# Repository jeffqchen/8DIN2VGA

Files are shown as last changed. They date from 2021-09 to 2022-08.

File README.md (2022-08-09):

# 8DIN2VGA

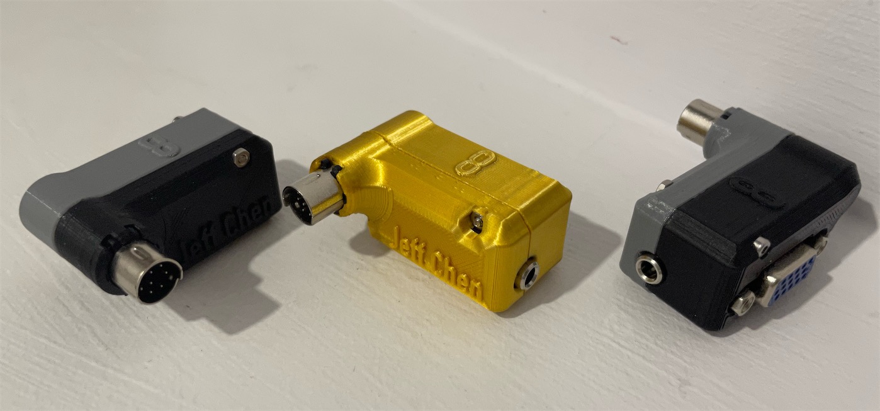
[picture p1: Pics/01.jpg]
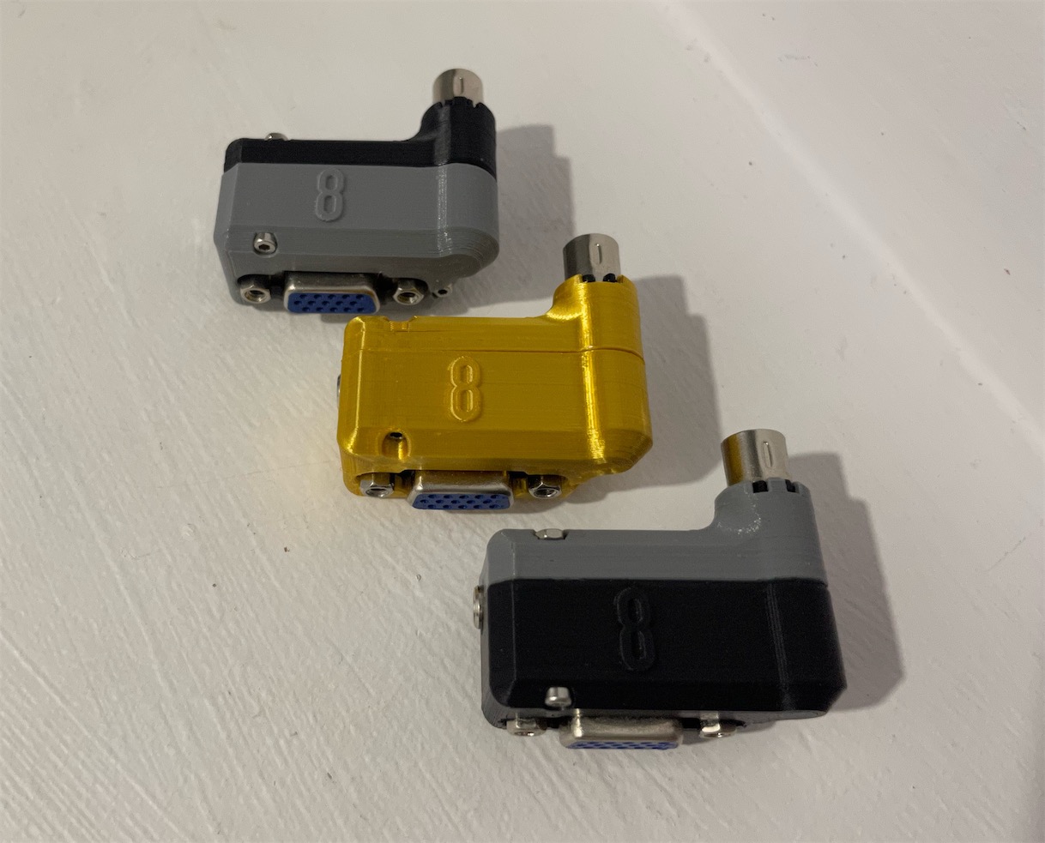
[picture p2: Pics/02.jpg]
 

A dongle for console with 8 pin Mini DIN RGBs video output.

------

This adapter allows you to plug into consoles that outputs RGBs and audio via a 8 pin Mini DIN jack and transmit the signals through a VGA cable. This includes but not limited to:
- NESRGB modded NES/Famicom
- 3DORGB modded with 3DORGB and 8 pin Mini DIN option
- Certain supergun boards

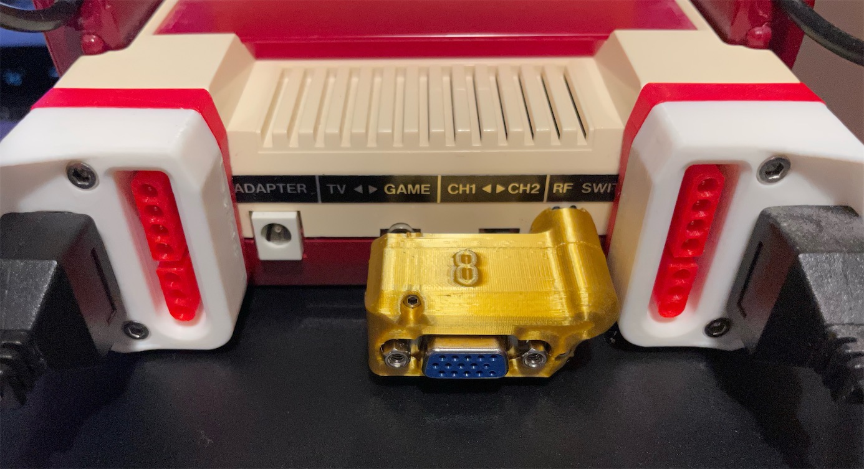
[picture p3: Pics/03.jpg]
 

 Audio can be sent within the VGA cable, or extracted from the 3.5mm jack on the dongle. Buzzing may be noticeable when audio is transmited through the VGA cable in certain scenes in certain games. This is due to insufficient shielding in most VGA cables. If you find the buzzing to be annoying, please use the 3.5mm jack on the dongle for audio output. This will ensure the cleanest possible audio.

-----------

## Different Designs

There are two types of 8 pin Mini DIN connectors you can purchase. One typically used for building cables, the other that's directly soldered to the PCB. Hence I've made two distinct designs for each of them. Comparatively speaking, the PCB-type design is easier to assemble. Otherwise, they function perfectly the same.

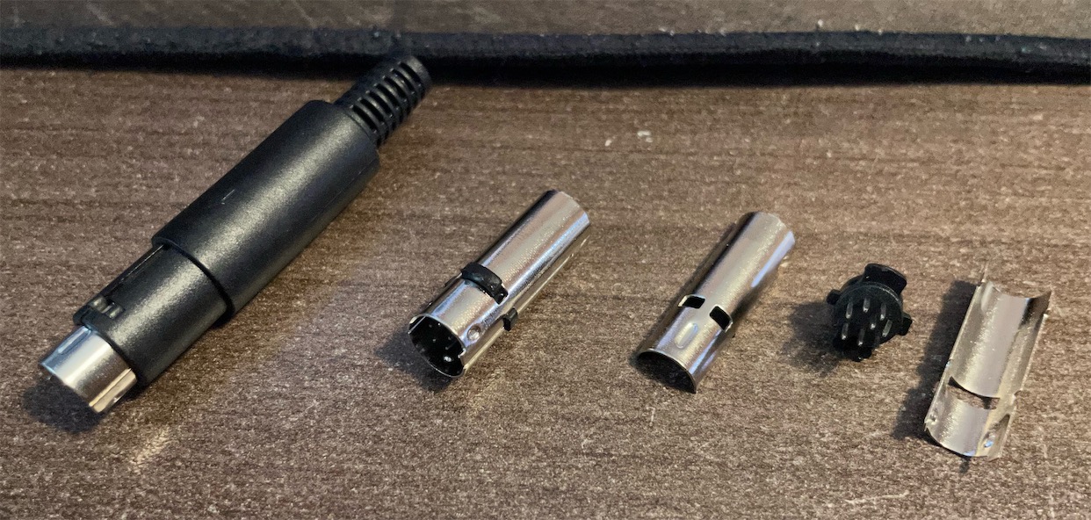
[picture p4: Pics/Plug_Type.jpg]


[Building Guide for Plug-Type 8DIN2VGA](./8DIN2VGA_Plug/README.md)

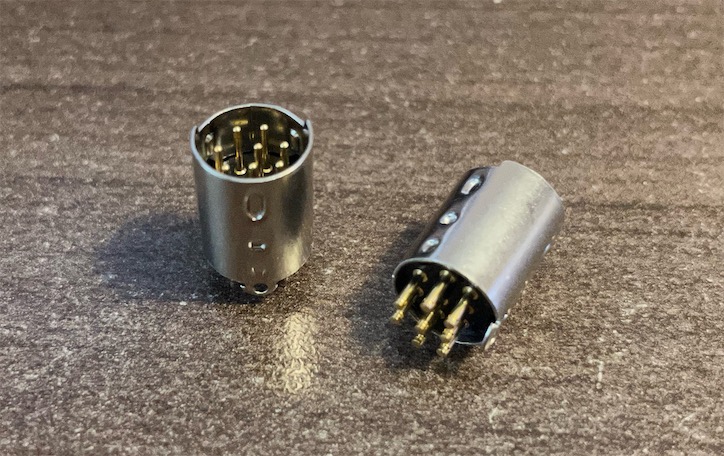
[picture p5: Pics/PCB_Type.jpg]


[Building Guide for PCB-Type 8DIN2VGA](./8DIN2VGA_PCB/README.md)

-----------

Shield: [][cc-by-sa]

This work is licensed under a
[Creative Commons Attribution-ShareAlike 4.0 International License][cc-by-sa].

[][cc-by-sa]

[cc-by-sa]: http://creativecommons.org/licenses/by-sa/4.0/
[cc-by-sa-image]: https://licensebuttons.net/l/by-sa/4.0/88x31.png
[cc-by-sa-shield]: https://img.shields.io/badge/License-CC%20BY--SA%204.0-lightgrey.svg

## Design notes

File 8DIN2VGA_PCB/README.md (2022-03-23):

# 8DIN2VGA PCB-Type
-----------
## Parts

- PCB
  - [Main](https://oshpark.com/shared_projects/Ayo7RfDd)
  - [Plug Sub PCB](https://oshpark.com/shared_projects/sRWPes9V)

- 8 pin Mini DIN Male (PCB Type) - Choose the "8 Pin" option - [Link](https://github.com/jeffqchen/JeffParts/blob/main/Connectors/Mini%20DIN/8Pin/Through%20Hole/info.md)

*Note: the "9 Pin" option is incompatible with the Genesis, if you are wondering. Don't buy it.*

- VGA Port Slim Female - [Link](https://github.com/jeffqchen/JeffParts/blob/main/Connectors/HD15/Slim/Female%20PCB/info.md)

- 3.5mm Headphone Jack - [Link](https://github.com/jeffqchen/JeffParts/blob/main/Connectors/3.5mm%20Audio%20Jack/Vertical%205-Pin%20PCB/info.md)

- [1x] ]M2x20mm and [1x] M2x16mm screw and hex nut - [Link](https://github.com/jeffqchen/JeffParts/blob/main/Parts/M2%20M3%20Hex%20Screw%20%26%20Nut/info.md)

- 2x SMD Capacitor 10uF 6.3V 0603 size

- 3D Printed Case and Insert

-----------
## Print

Print the parts in their original orientations, with the mating surface downwards. Print with support.

-----------
## Assembly

Trim all the extra tabs on the PCB and file them flush to ensure an easy assembly.

First, insert the main PCB golden fingers into the plug PCB as indicated in the photos.

Adjust the position to ensure the mating is flush. If not, try filing off some more of the PCB.

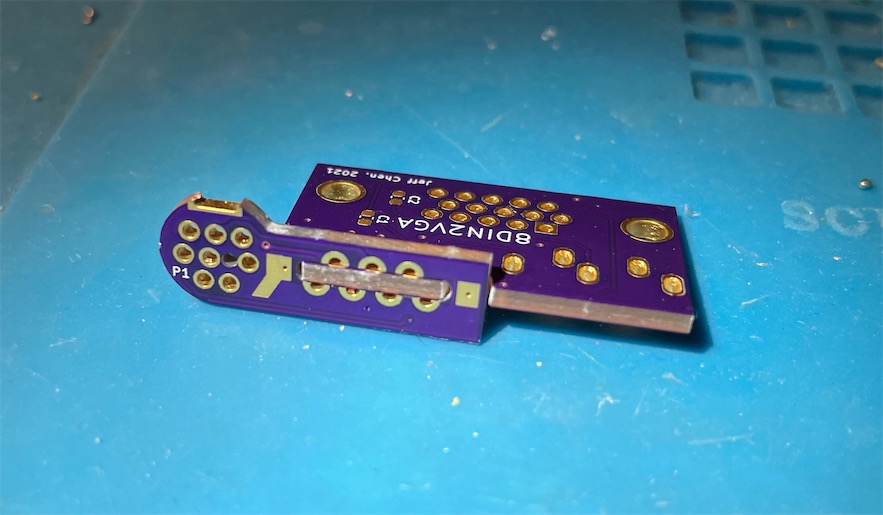
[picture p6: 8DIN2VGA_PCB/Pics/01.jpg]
 

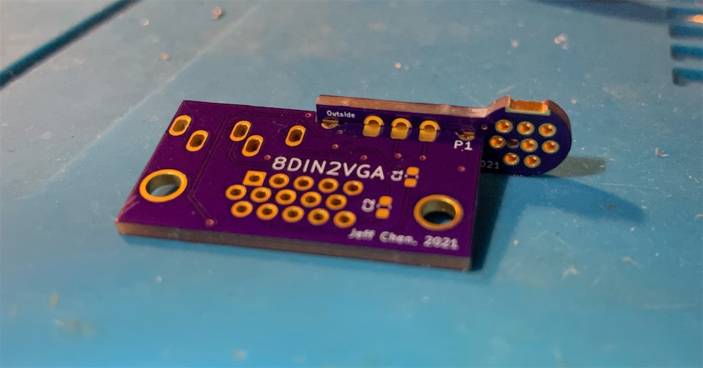
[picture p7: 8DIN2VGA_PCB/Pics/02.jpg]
 

Make sure the main and the plug PCBs are perpendicular. Then tac it down by soldering only one contact. Then inspect again. If something is not right, adjust while keeping your iron on the soldered joint to keep it molten.

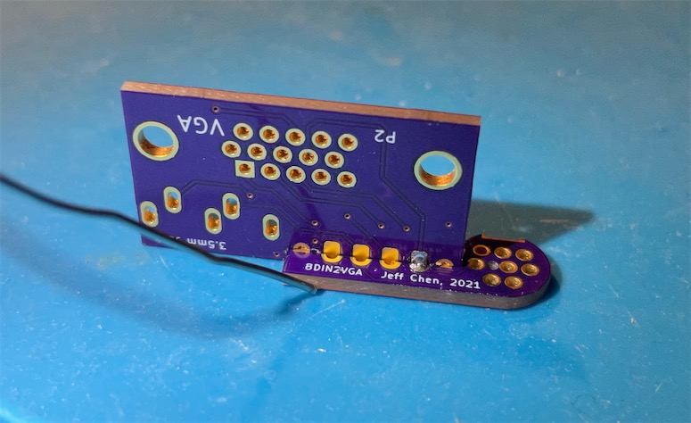
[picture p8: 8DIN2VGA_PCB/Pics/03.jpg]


Once satisfied, solder down all the contacts between the main and the plug PCB. Then solder on the 0603 10uF capacitors onto the main PCB .

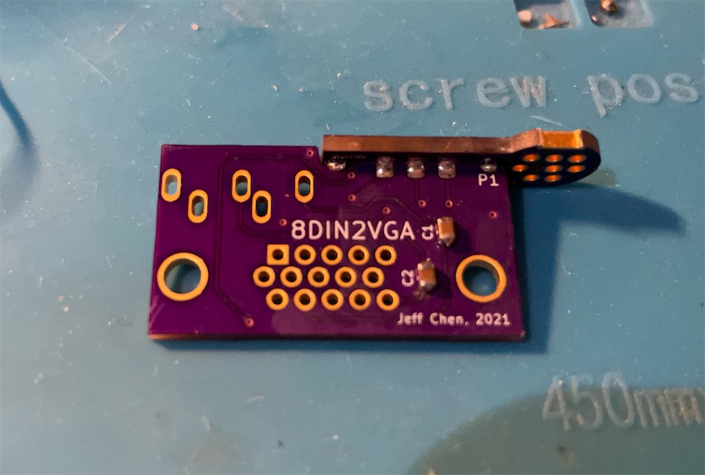
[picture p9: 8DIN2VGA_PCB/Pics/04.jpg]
 

Insert the 8 pin DIN plug into the plug PCB. Tac one joint down with solder.

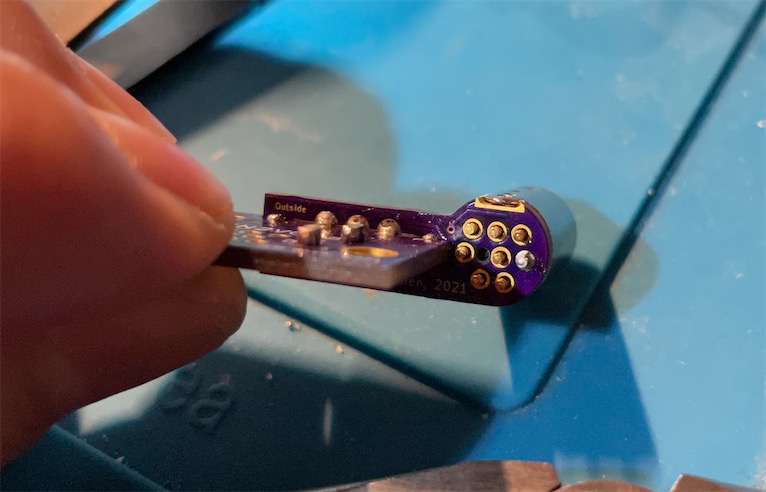
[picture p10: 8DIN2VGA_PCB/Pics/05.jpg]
 

 Check if the plug is soldered on straight, adjust if necessary.

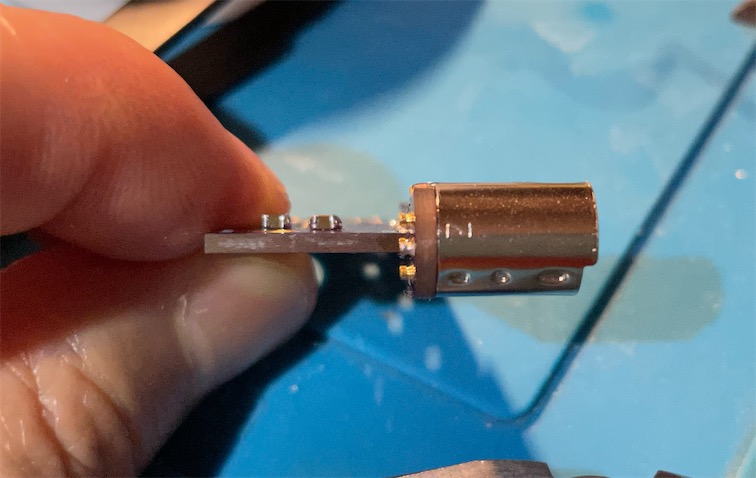
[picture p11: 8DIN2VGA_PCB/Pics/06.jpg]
 

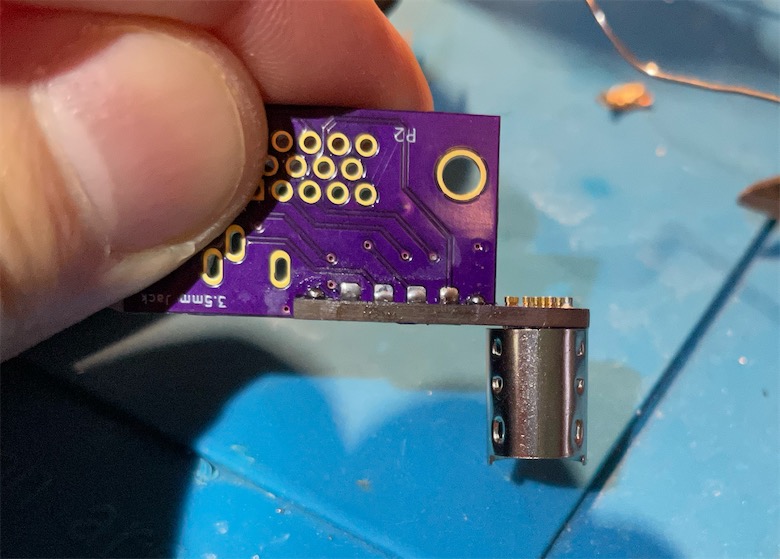
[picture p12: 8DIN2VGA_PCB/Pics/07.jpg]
 

Then solder all the contacts of the plug to the PCB.

Right next to the plug, on the PCB, there is an exposed area of copper. Drown it with copper and solder it to the metal shielding to add more mechanical strength to the assembly.

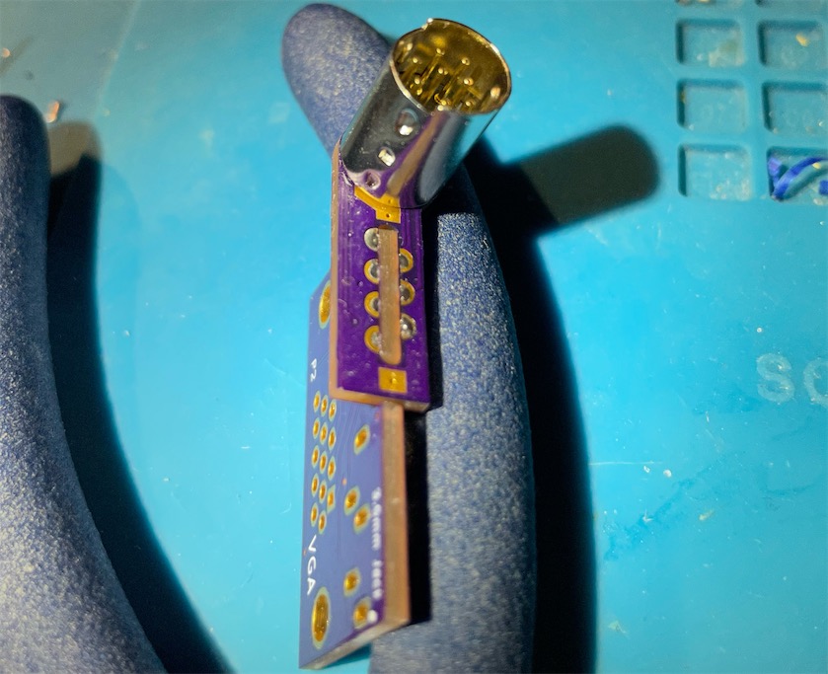
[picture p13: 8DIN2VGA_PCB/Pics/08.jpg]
 

 Don't forget to solder the metal tab on top of the shielding to the PCB for even more strength.

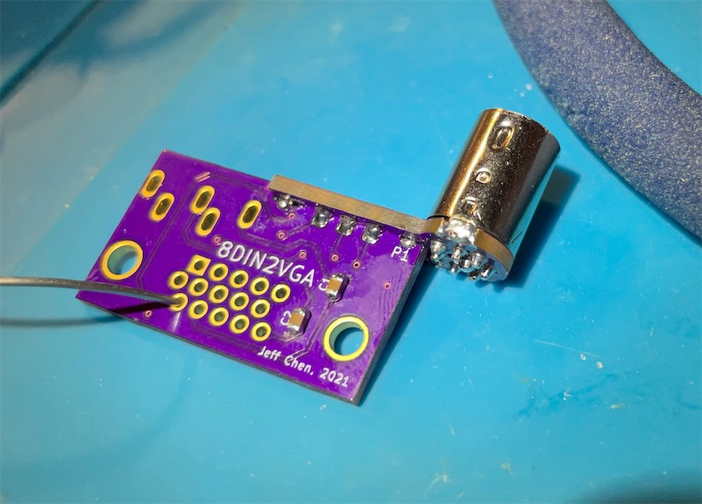
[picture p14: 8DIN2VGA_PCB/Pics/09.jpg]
 

 Insert the 3.5mm jack into the PCB. Solder it down by only one lead and adjust it to make sure it's flush to the PCB. Then solder all the contacts.

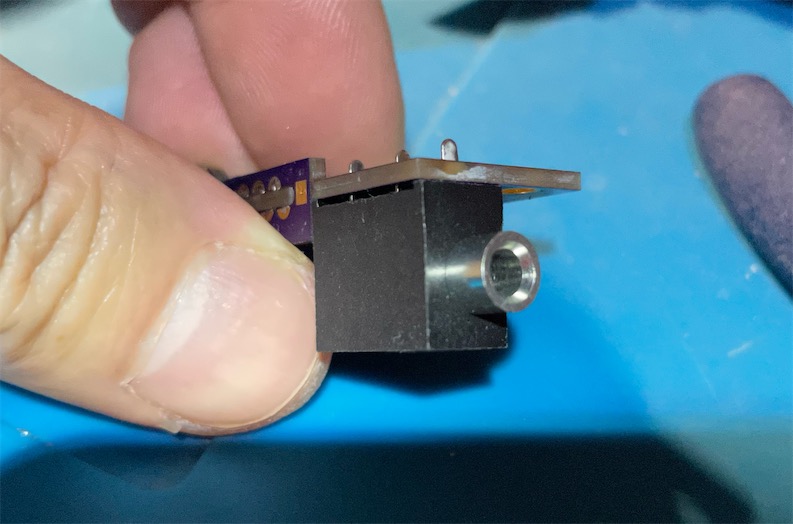
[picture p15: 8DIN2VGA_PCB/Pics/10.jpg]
 

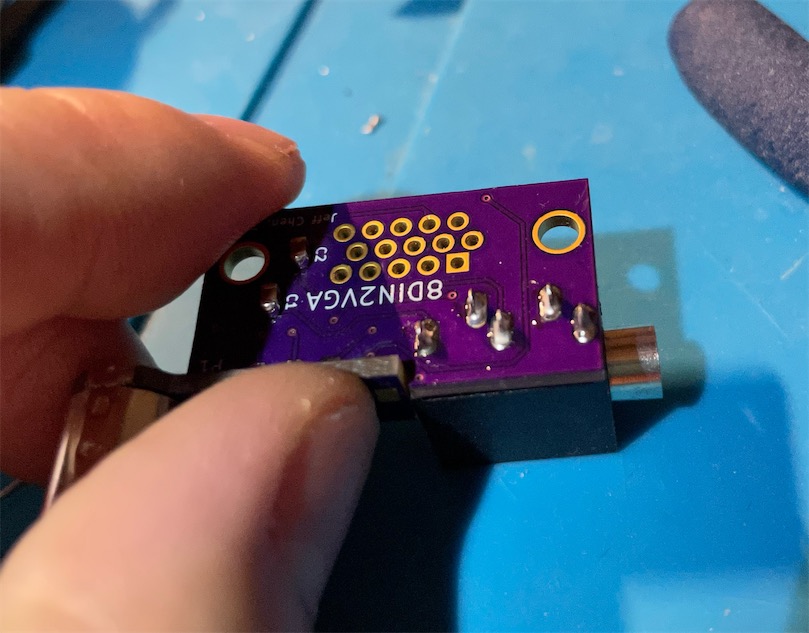
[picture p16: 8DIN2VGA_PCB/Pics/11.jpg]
 

Insert the assembly into the inside shell. You might have to push a bit hard if the printing tolerance is tight. Then, fit in the 3D printed insert piece. It should be flush with the outside of the 3.5mm jack.

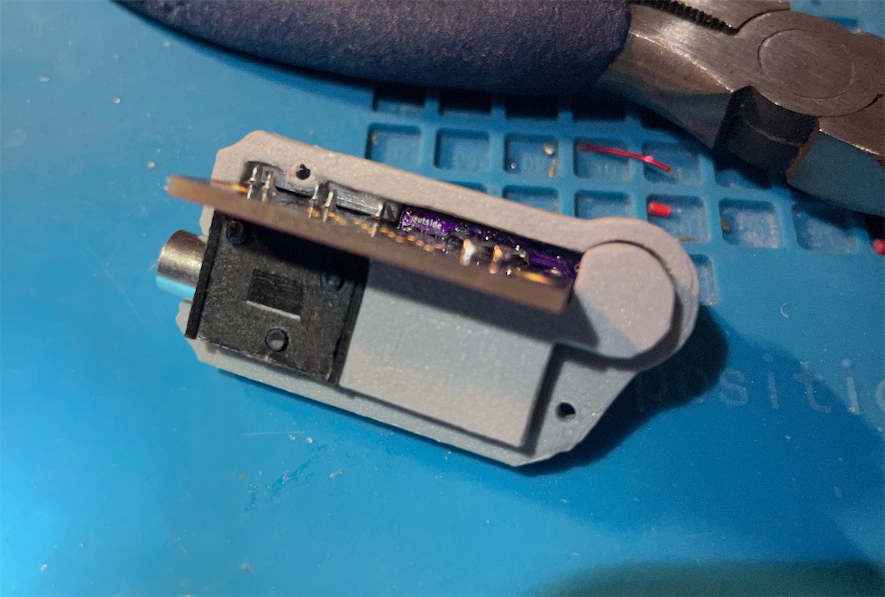
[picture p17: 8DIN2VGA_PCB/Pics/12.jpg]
 
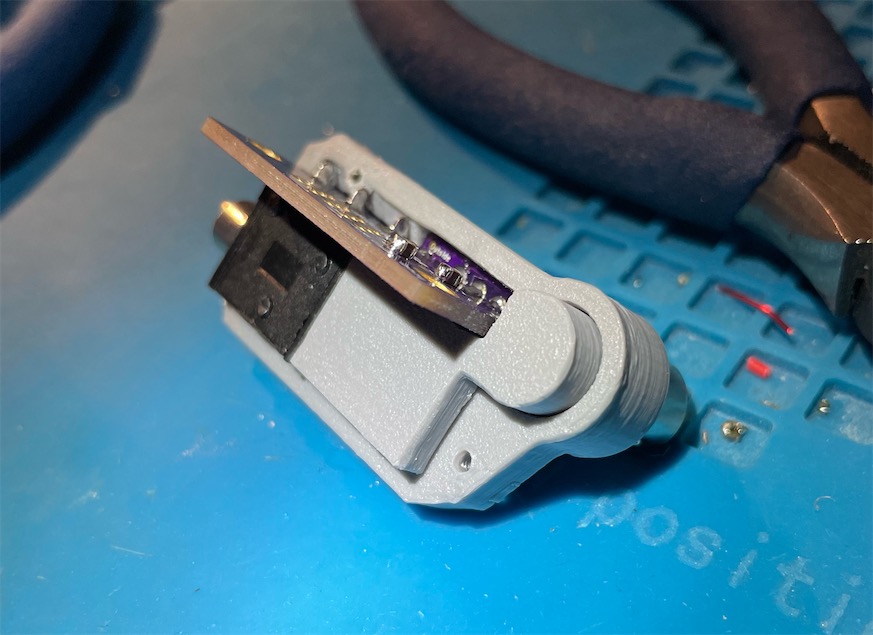
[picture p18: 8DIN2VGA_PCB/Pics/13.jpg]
 

Test fit the outside shell and see if the shells close nicely together. If not, check the fitment.

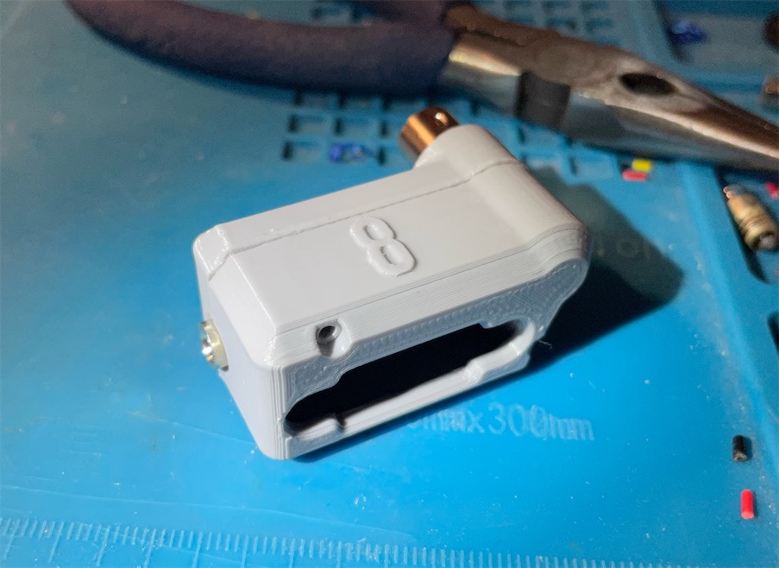
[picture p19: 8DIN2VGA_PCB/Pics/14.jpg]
 

Open the shell back up and finally, solder in the VGA port.

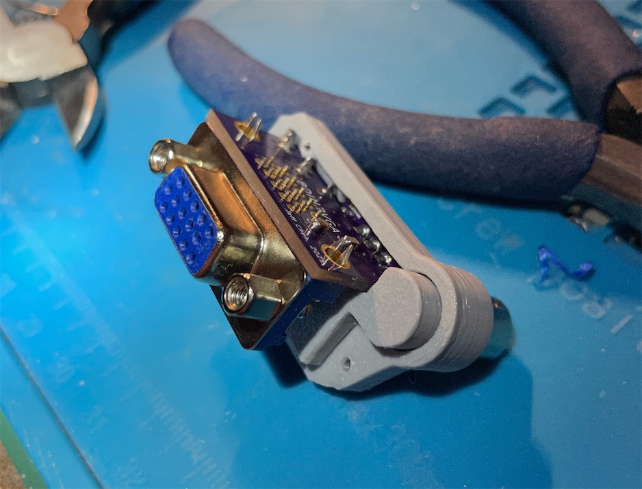
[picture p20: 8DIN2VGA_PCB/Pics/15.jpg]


Alternatively, you can slide out the entire assembly and solder the VGA port. It's also easier to test in this state.

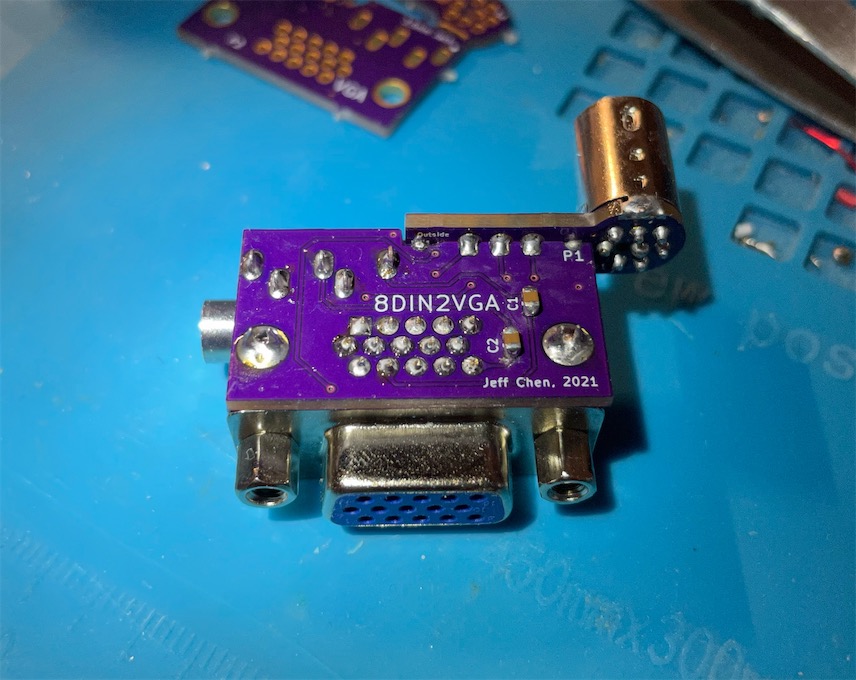
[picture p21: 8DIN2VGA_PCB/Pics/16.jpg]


Remember to put in the insert piece inside when you close up the shell.

If nuts don't want to fit nicely into the shell, twist a screw onto it and use it as a handle and try to press the nut in place from the outside.

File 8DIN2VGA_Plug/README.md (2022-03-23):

# 8DIN2VGA Plug-Type
-----------

## Parts

- PCB
  - [Main](https://oshpark.com/shared_projects/XZ4A1SB4)
  - [Top Sub **0.8mm thickness**](https://oshpark.com/shared_projects/FF7H08du)
  - [Bottom Sub **0.8mm thickness**](https://oshpark.com/shared_projects/HFqqnMif)

*Note the Top & Bottom sub boards MUST be ordered with the 0.8mm thickness option, otherwise they won't fit!*

- 8 pin Mini DIN Male (Plug Type) - [Link](https://github.com/jeffqchen/JeffParts/blob/main/Connectors/Mini%20DIN/8Pin/Cable/info.md)

- VGA Port Slim Female - [Link](https://github.com/jeffqchen/JeffParts/blob/main/Connectors/HD15/Slim/Female%20PCB/info.md)

- 3.5mm Headphone Jack - [Link](https://github.com/jeffqchen/JeffParts/blob/main/Connectors/3.5mm%20Audio%20Jack/Vertical%205-Pin%20PCB/info.md)

- M2x20mm screw and hex nut - [Link](https://github.com/jeffqchen/JeffParts/blob/main/Parts/M2%20M3%20Hex%20Screw%20%26%20Nut/info.md)

- 2x SMD Capacitor 10uF 6.3V 0603 size

-----------
## Print

Print the parts with the mating surface downwards, with support.

-----------
## Assembly

Soldering in this project is essential and somewhat challenging. This applies to soldering the sub boards to the pin header, as well as the landing pads on the main PCB. If you leave any gap, the assembly will not fit and the shells won't close properlly.

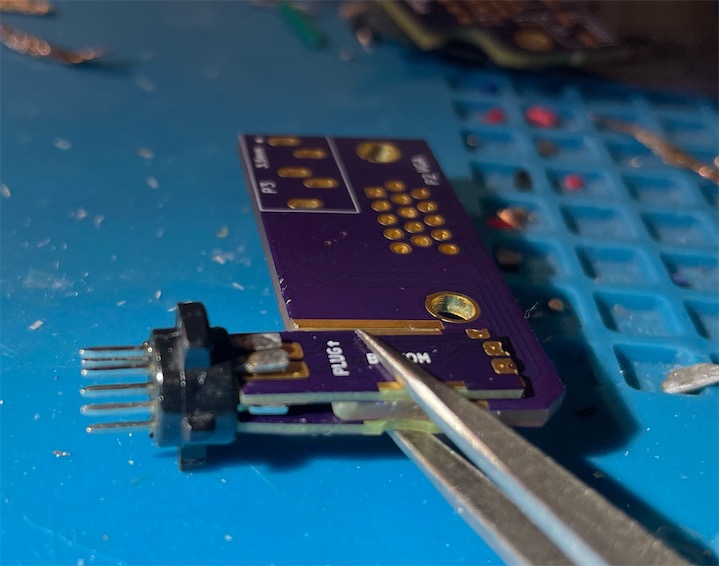
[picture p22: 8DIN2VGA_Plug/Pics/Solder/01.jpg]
 
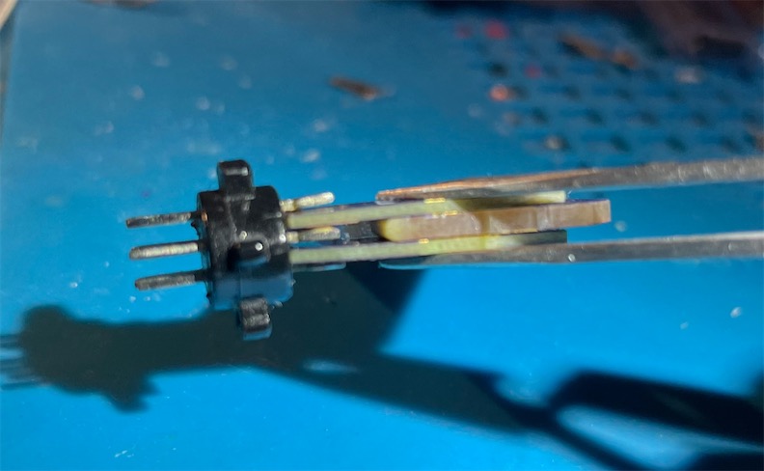
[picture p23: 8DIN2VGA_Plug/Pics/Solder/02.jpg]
 

 First, put the 3 boards together in their final position, and fix the assembly with the help from reverse tweezers or clamps. Try and fit the 0.8mm PCBs in between the gaps between the back side of the 3 rows of pins. Push the sub PCBs all the way until they touch the pin header. Make sure the pins and their pads are aligned properlly.

 ----

 ## IMPORTANT

 *The plastic of the plug pin header is weak against heat and should not be heated for more than a few seconds in one go. Try to cool it down between soldering by blowing air on it.*

 ----

 Solder the two pins on the bottom side of the bottom PCB with proper amount of solder. Then release the clamping and remove the top and main PCB. Proceed to solder the center row of the pins to the bottom PCB.

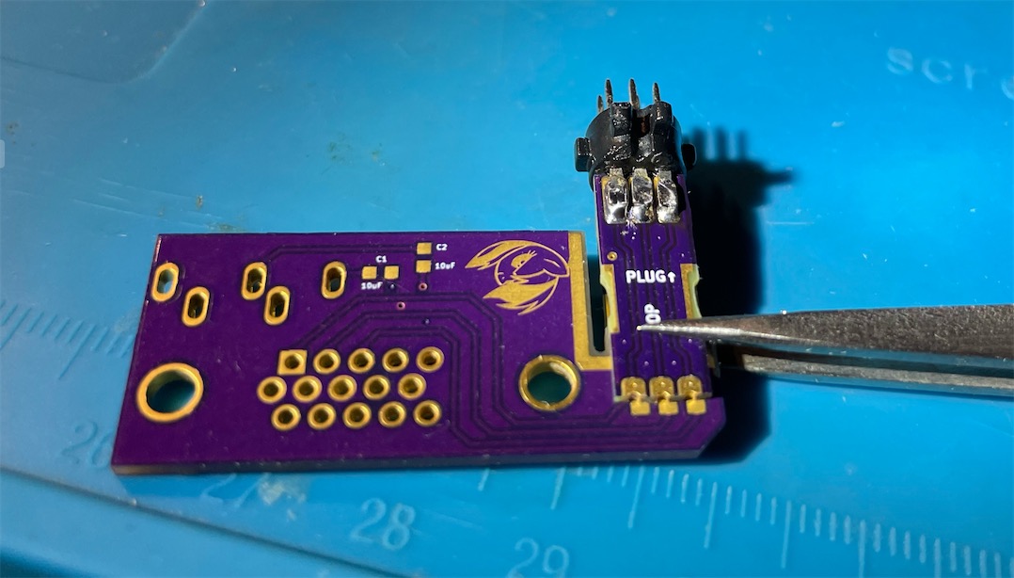
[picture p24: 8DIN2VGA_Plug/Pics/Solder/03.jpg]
  

 Again, put everything back together with clamping. Then, solder the top PCB to the top row of the pin header. Now, release the clamping and remove only the main PCB. The assembly should look as follows:

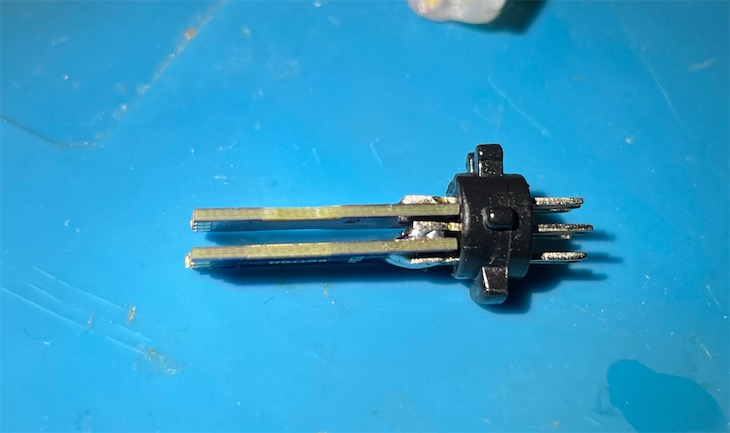
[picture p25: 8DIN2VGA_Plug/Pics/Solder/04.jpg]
 

 Now, put the 2 pieces of metal shielding over the pin header part:

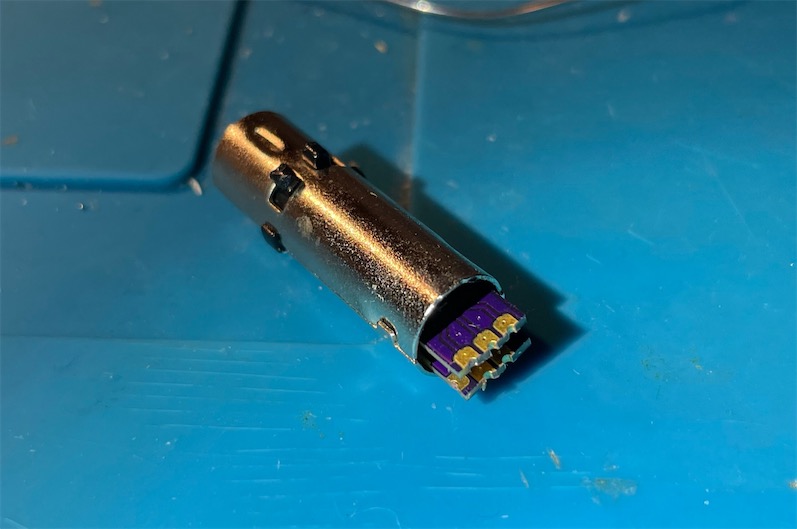
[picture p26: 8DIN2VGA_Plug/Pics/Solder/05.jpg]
 

 Shove the assembly through the round hole on the inside shell, all the way in:

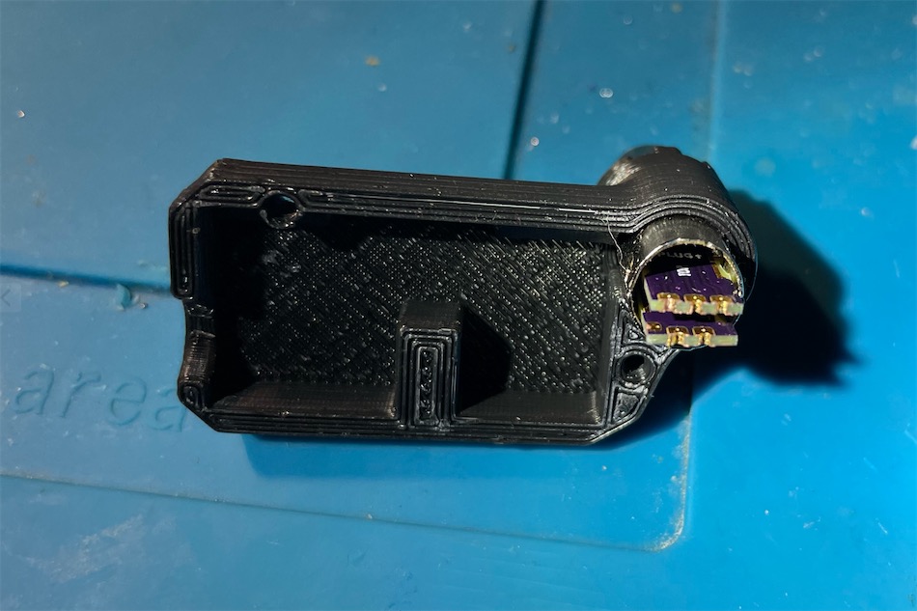
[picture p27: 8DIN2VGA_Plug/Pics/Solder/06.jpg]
 

 Test fit the main PCB firmly into the shell and the plug and see if all the landing pads line up correctly:

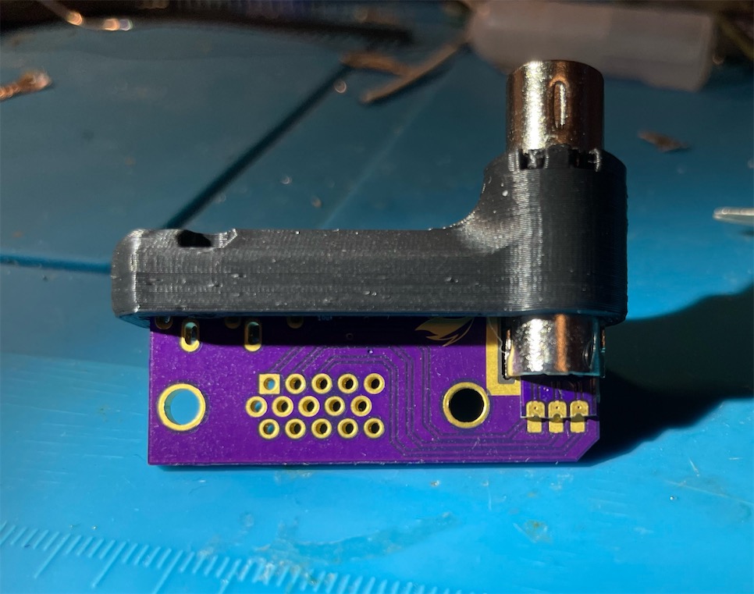
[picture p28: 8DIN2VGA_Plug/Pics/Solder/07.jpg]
 
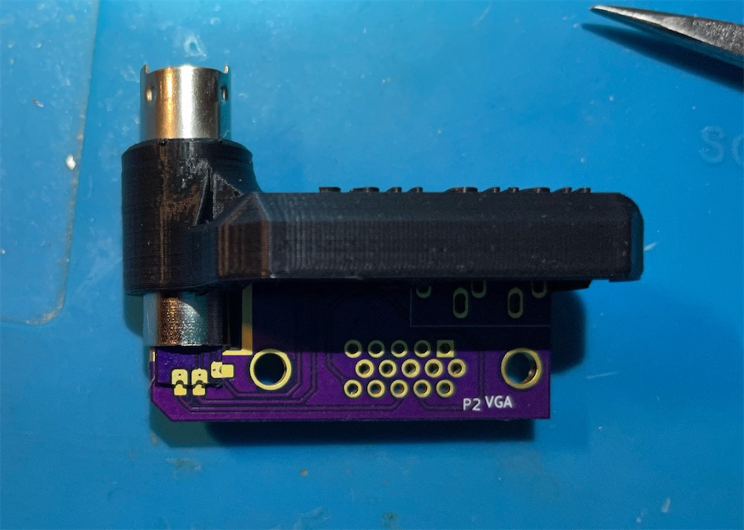
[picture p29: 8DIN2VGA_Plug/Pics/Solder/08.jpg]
 

 Now, take out the main PCB and solder on the 10uF SMD caps and the headphone jack:

 

 Again, insert the main PCB into its final position. Pinch the two sub boards into the main with a clapm or reverse tweezers. Make sure there's no gap between the sub and main PCB. Then, solder all the landing pads with proper amount of solder.

 
 

 Then, use ample amount of solder to attach the metal shield of the plug to the exposed copper area onto both sides of the main PCB。

 
 

 Last, solder in the VGA port. Soldering is done.



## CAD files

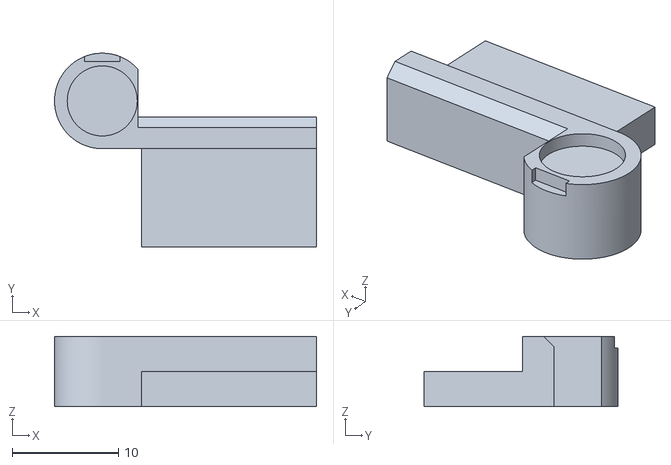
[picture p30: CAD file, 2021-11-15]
8DIN2VGA_PCB/3D Print/Insert.stl
24.7 x 18.2 x 6.60

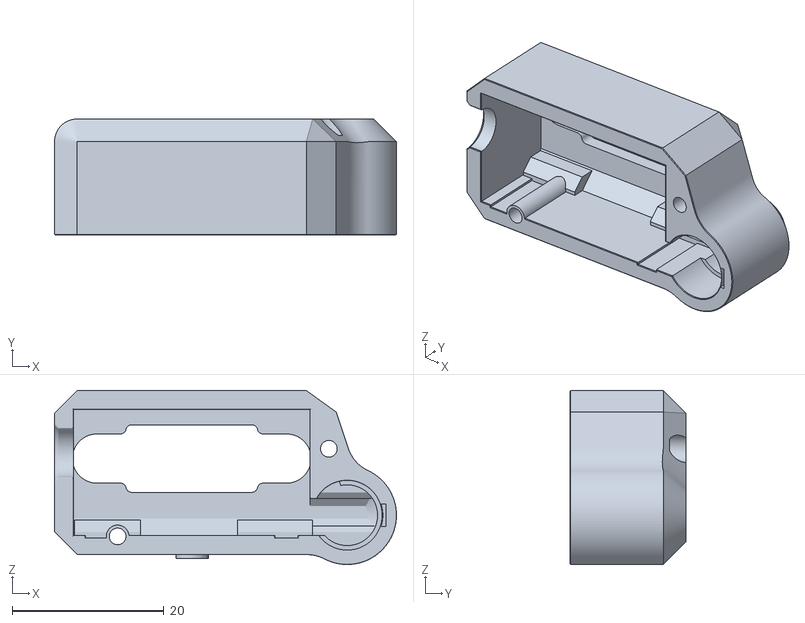
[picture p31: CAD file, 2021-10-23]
8DIN2VGA_Plug/3D Print/Outside.stl
45.1 x 15.3 x 22.9

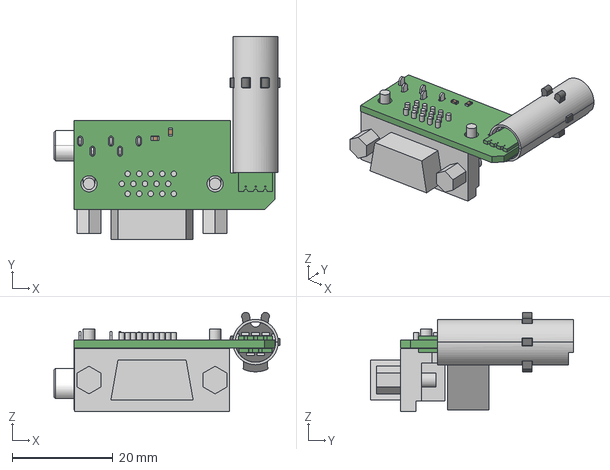
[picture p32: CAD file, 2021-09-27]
8DIN2VGA_Plug/KiCAD/8DIN2VGA.step
44.8 x 40.3 x 19.7 mm

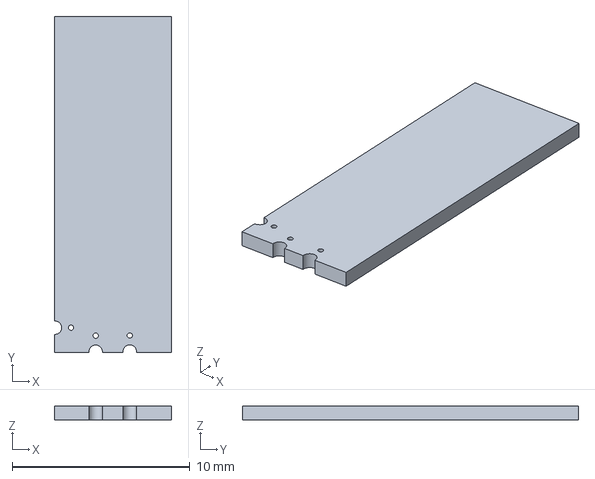
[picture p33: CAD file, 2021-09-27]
8DIN2VGA_Plug/KiCAD/8DIN2VGA_Bottom/8DIN2VGA_Bottom.step
6.61 x 18.9 x 0.8 mm

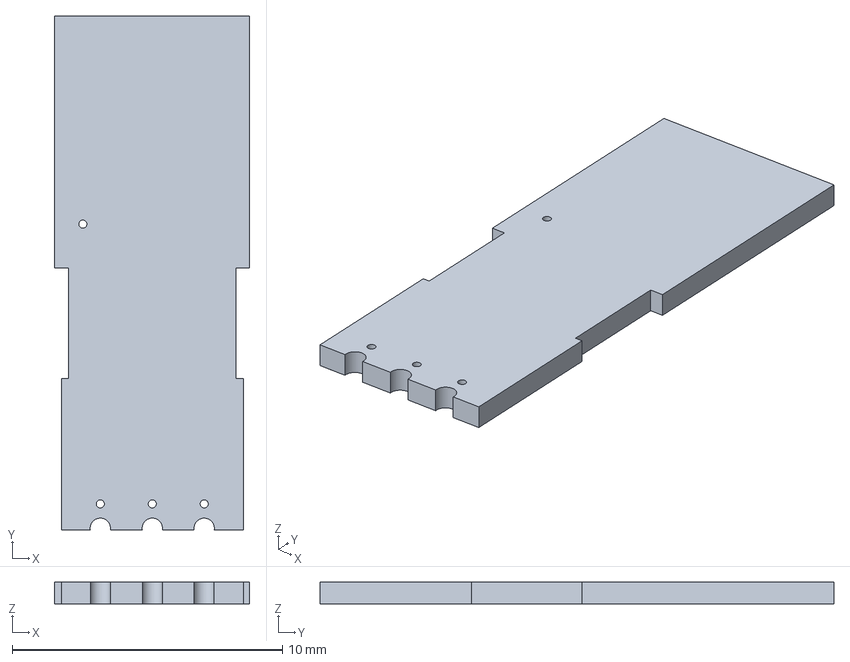
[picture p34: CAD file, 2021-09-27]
8DIN2VGA_Plug/KiCAD/8DIN2VGA_Top/8DIN2VGA_Top.step
7.22 x 19.0 x 0.8 mm

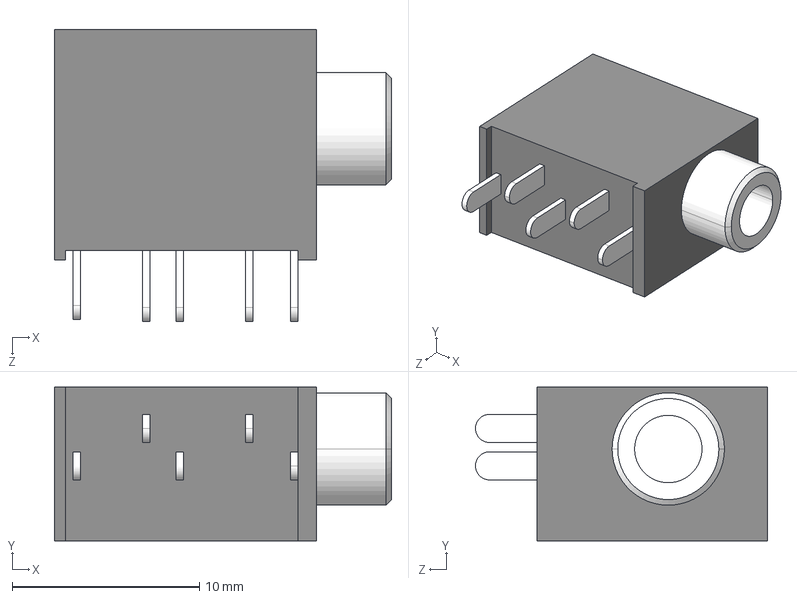
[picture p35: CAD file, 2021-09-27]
8DIN2VGA_Plug/KiCAD/Materials/3.5MM_vertical_SJ1-3535N/3.5MM_vertical_SJ1-3535N_3D/CUI_DEVICES_SJ1-3535N.step
18.0 x 8.20 x 15.6 mm

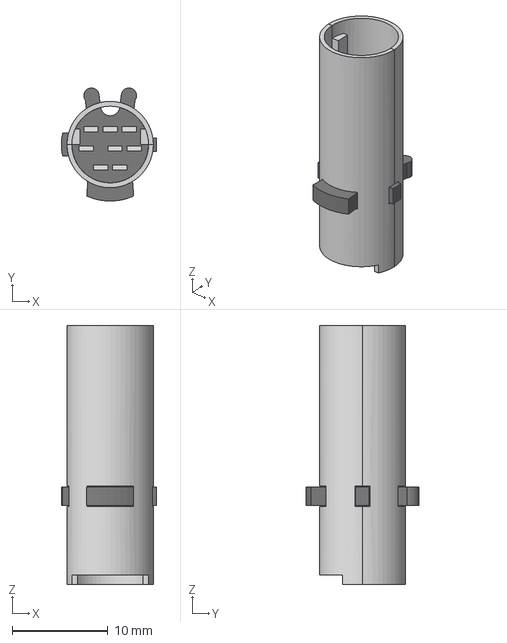
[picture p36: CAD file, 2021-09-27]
8DIN2VGA_Plug/KiCAD/Materials/Mini DIN 8 pin.step
9.95 x 11.8 x 27.0 mm
Shield Top
Shield Bottom

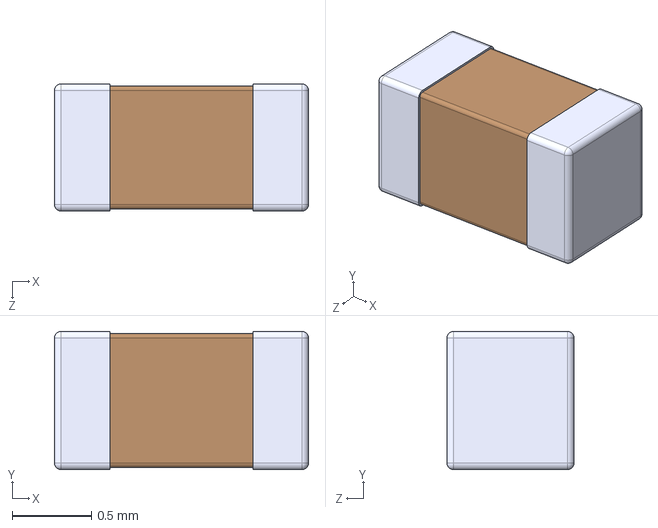
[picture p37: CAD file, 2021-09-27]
8DIN2VGA_Plug/KiCAD/Materials/SMD_Cap/C0603C180K4HAC7867.step
1.60 x 0.87 x 0.8 mm

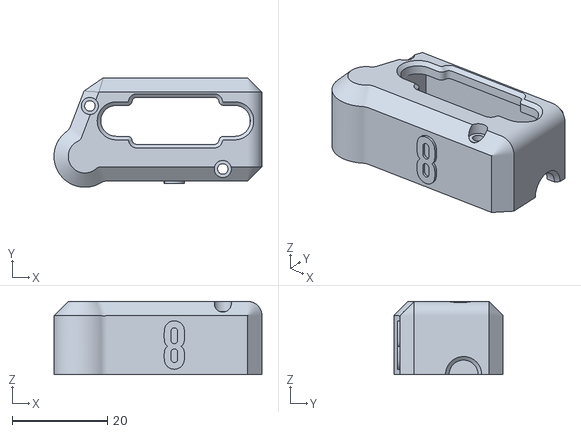
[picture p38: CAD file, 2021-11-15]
8DIN2VGA_PCB/3D Print/Shell Outside.stl
43.8 x 23.0 x 15.4

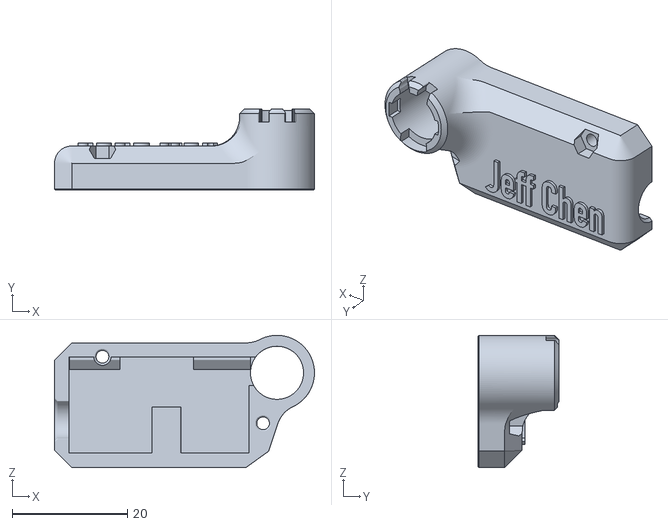
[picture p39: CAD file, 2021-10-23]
8DIN2VGA_Plug/3D Print/Inside.stl
45.1 x 14.0 x 22.9

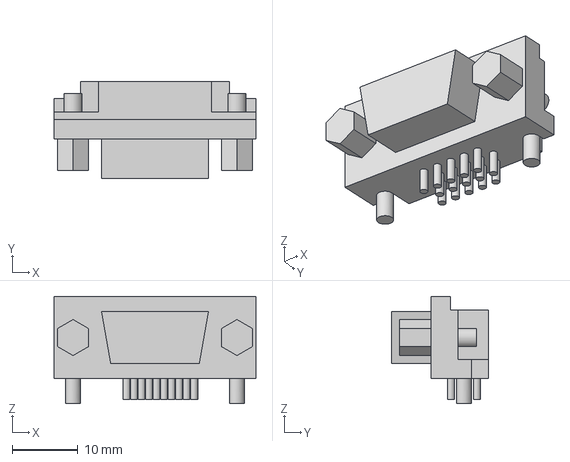
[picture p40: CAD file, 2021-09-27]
8DIN2VGA_Plug/KiCAD/Materials/VGA Female Slim.step
30.8 x 14.8 x 16.4 mm

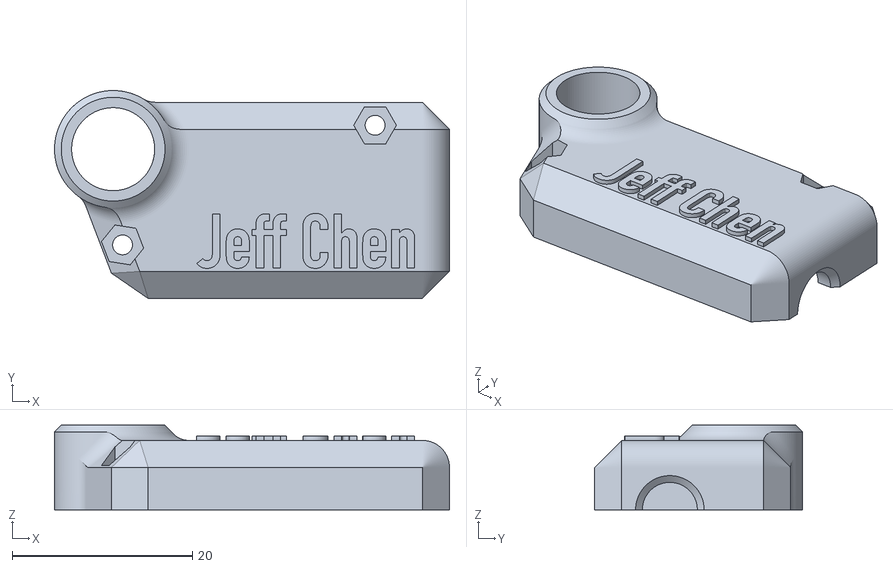
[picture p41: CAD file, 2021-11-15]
8DIN2VGA_PCB/3D Print/Shell Inside.stl
43.8 x 23.0 x 9.40

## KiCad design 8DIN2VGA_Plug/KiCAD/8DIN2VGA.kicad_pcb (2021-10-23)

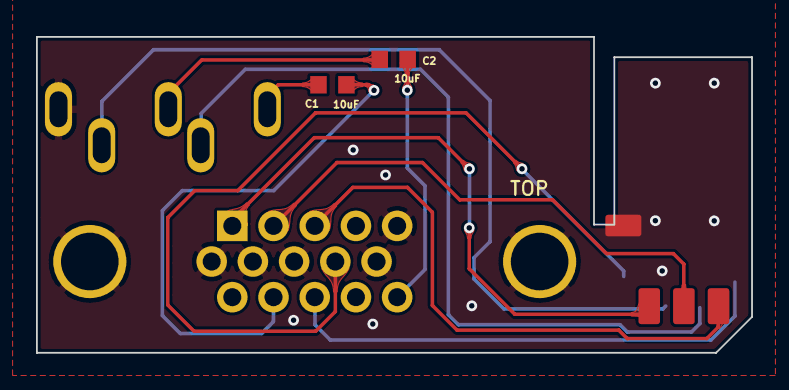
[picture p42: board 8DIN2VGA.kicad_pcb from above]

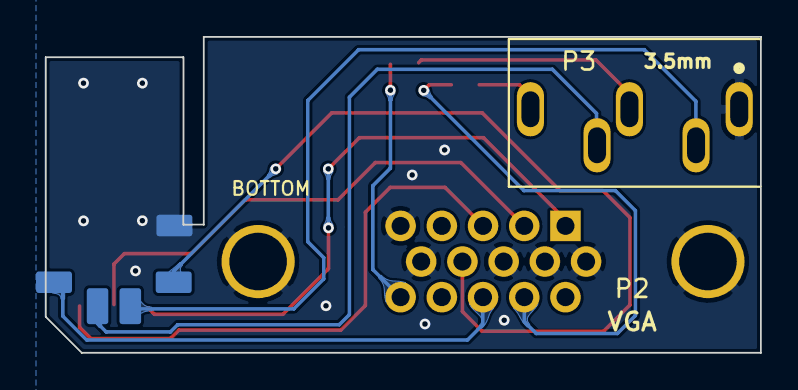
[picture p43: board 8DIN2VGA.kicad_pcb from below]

Board: 2 copper layers, 39.7 x 17.5 mm, 5 parts (2 on the bottom side), 12 nets.

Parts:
C1, C2: 10uF; CAP_SMD_0603
P1: 8_pin_DIN_Landing; 8DIN_Landing
P2: VGA; VGA_female_rightangle_slim
P3: 3.5mm_vertical

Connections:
/+5V: P1.5, P2.9
/Audio_L_VGA: C1.2, P2.12
/Audio_L_to_Jack: P1.2, P3.2
/Audio_L_to_VGA: C1.1, P3.4
/Audio_R_VGA: C2.1, P3.5
/Audio_R_to_Jack: P1.1, P3.3
/BLUE: P1.6, P2.3
/GREEN: P1.7, P2.2
/RED: P1.8, P2.1
/SYNC: P1.3, P2.13
GND: P1.4, P2.5, P2.6, P2.7, P2.8, P2.10, P2.S1, P2.S2, P3.1
unnamed: C2.2, P2.15

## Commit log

2021-09-27 Initial Upload
    [8DIN2VGA-B_Mask.gbr, 8DIN2VGA-B_Paste.gbr, 8DIN2VGA-B_SilkS.gbr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]
2021-10-23 Update with new 5V design
    [8DIN2VGA-B_Mask.gbr, 8DIN2VGA-B_Paste.gbr, 8DIN2VGA-B_SilkS.gbr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]
2021-10-23 Update 3D printed shell
    [Inside.stl, Outside.stl]
2021-11-15 Add Neo 8DIN2VGA & Reorganize Files
    [8DIN2VGA-B_Mask.gbr, 8DIN2VGA-B_Paste.gbr, 8DIN2VGA-B_SilkS.gbr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]
2021-11-15 Readme for neo 8din2vga
    [Insert.stl, Shell Inside.stl, Shell Outside.stl]

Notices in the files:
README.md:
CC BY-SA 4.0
